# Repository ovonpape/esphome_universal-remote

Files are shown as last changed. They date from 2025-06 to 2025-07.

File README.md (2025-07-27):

# HassBeam
A cheap and easy to use universal remote that can be integrated into Home Assistant using ESPHome.  
It allows you to replace your pile of different remote controls with one stationary device that can be controlled via Home Assistant. Of course, you can also automate the control of your IR devices.

<p float="left">
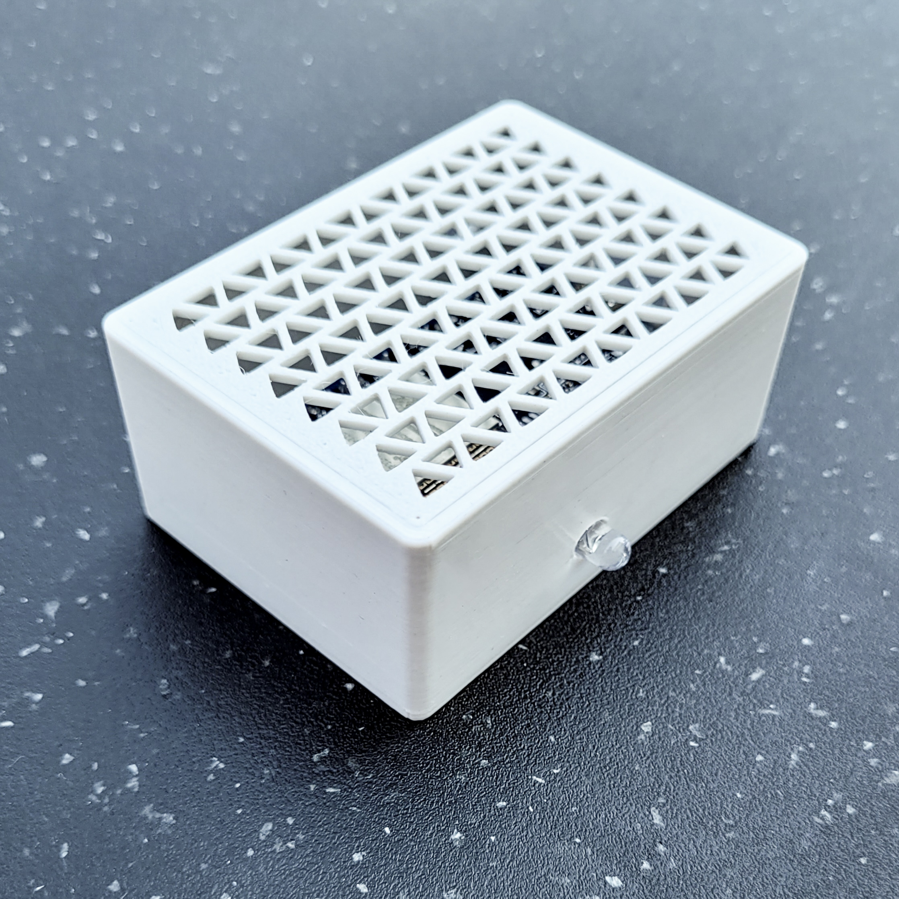
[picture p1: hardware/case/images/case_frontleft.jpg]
case_frontleft
  
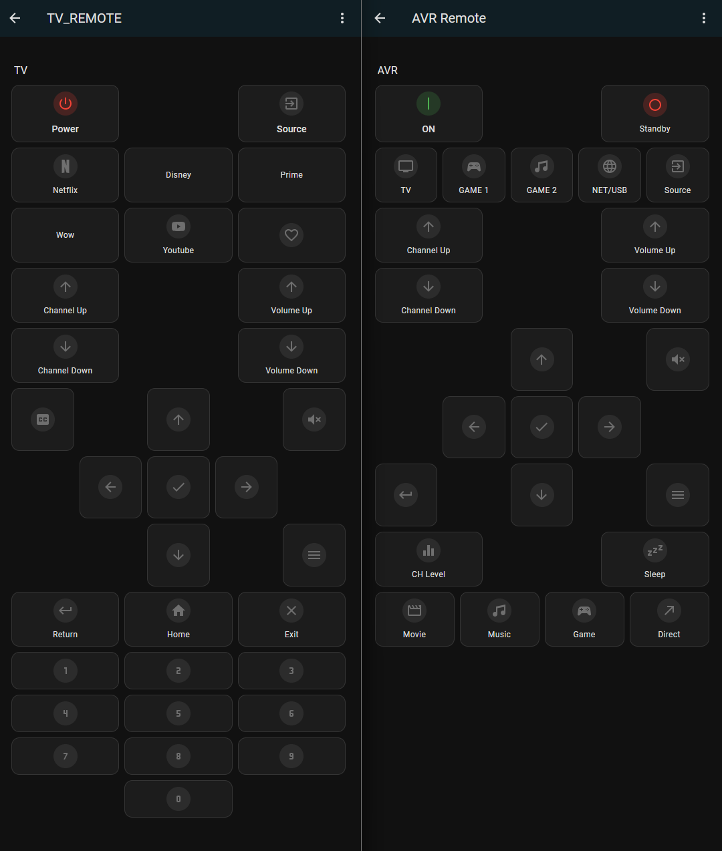
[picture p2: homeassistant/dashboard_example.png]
Dashboard Example
  
</p>

#### With the new [HassBeam Connect integration](#hassbeam-connect), configuring your system is faster and simpler than ever:
<p float="left">
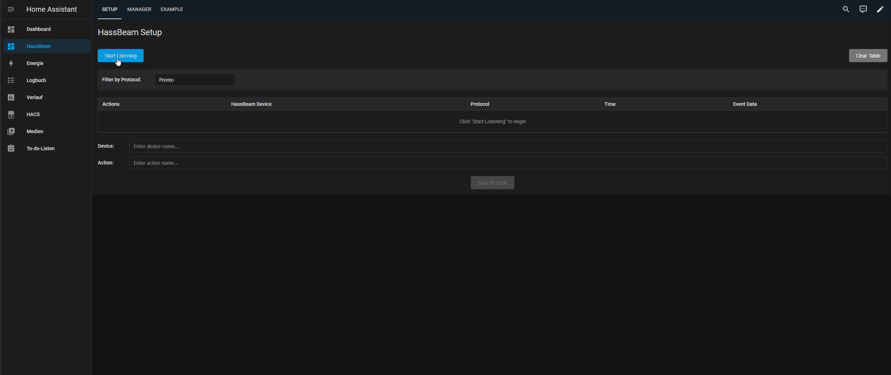
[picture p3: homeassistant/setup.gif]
setup process
  
</p>

## ✅  Requirements
To use this project, you will need a working [Home Assistant](https://www.home-assistant.io/) instance, as the universal remote integrates directly with it. The core of the device is an ESP micro controller, which communicates with Home Assistant via [ESPHome](https://esphome.io/).

In addition to the ESP, a few electronic components are required — see the [Parts](hardware.md#parts) section for details. 

Optionally, design files for a custom PCB or perfboard layout are provided, along with a 3D-printable case for the device.

<br>

## 🚀 Getting Started

To get started with the ESPHome Universal Remote, you will need to assemble the necessary hardware and flash the ESP32 with the appropriate configuration using ESPHome.

### ⚙️ Hardware Guide
The universal remote is fairly simple to build and use.  
Read the [Hardware Guide](hardware.md) for instructions on what you need and how to build it.

### 🛠️ Setup Guide

Once your hardware is ready, read the [Setup Guide](setup.md) to learn how to install and use the project.

<br>

## 💬 Community & Support

For questions, feature requests, or to connect with other users, feel free to join the discussion on [Reddit](https://www.reddit.com/r/HassBeam/).

You can use the thread to:
- Ask for help with setup or troubleshooting
- Share ideas or request new features
- Report issues (in addition to GitHub Issues)
- Showcase your own HassBeam related projects

We’d love to hear your feedback and see what you build!

<br> 
<br>
<br>

## 🔗 Related Projects

#### HassBeam Connect
A quick and easy way to capture and manage your IR codes in Homeassistant:
  - [HassBeam Connect Backend](https://github.com/BasilBerg/hassbeam-connect-backend)
  - [HassBEam Connect Cards](https://github.com/BasilBerg/hassbeam-connect-cards)
</br>

Check out these projects that helped in the creation of this project:
- [ESPHome](https://github.com/esphome/esphome)  
  Used to configure and flash the ESP32. Also handles IR signal sending and receiving.

- [Home Assistant](https://github.com/home-assistant/core)  
  Serves as the central control hub for triggering IR commands and integrating the remote into smart home automations.

- [Mushroom](https://github.com/piitaya/lovelace-mushroom)  
  A modern and customizable UI component library for Home Assistant dashboards, used in the example configuration to create clean remote interfaces.

- [Fritzing](https://github.com/fritzing/fritzing-app)  
  Used to create the wiring diagrams and PCB layout.

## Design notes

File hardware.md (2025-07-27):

# HassBeam – Hardware

## Contents

- [Parts](#parts)
- [Assembly Options](#assembly-options)
- [Case](#case)

---

## Parts

To build the ESPHome Universal Remote, you’ll need:

- **Resistors**  
  Limit current through the IR LED and transistor. In this build: 11 Ohms for the LED, 1k Ohms for the transistor and 100 Ohms for the IR-Receiver. Choose a value based on the datasheets of your components.

- **Capacitor** (optional)
  A capacitor is used to filter high frequency noise. this improves reliability of the IR Receiver but is completely optional. In this example I'm using a 100nF capacitor.

- **IR LED**  
  Emits the infrared signals. Use a 940 nm LED for best compatibility. Narrow beam for focused control, wide for room coverage.

- **NPN Transistor**  
  Used to drive the LED safely, as ESPs GPIO pins can't handle high current.

- **IR Receiver**  
  Allows reading commands from existing remotes. The carrier frequency of most common IR protocols is 38kHz, so the receiver you pick should support that. In this example I'm using a TSOP4838

- **ESP microcontroller**  
    Any ESP microcontroller supported by ESPHome can be used, but you may need to adjust the wiring and case design to accommodate differences in pin layout and physical dimensions. In this example, an ESP32 WROOOM32 devboard is used

- **(Optional) Pin Headers**  
  Useful for detachable power or signal connections. If you want to build multiple HassBeams, you can make the receiver circuit modular to save cost and make the device smaller.

---

## Assembly Options

### Breadboard / Perfboard

The circuit can be assembled on a breadboard for prototyping. For a more permanent installation, you can solder the components onto a perfboard or use a custom PCB.  
The images below serve as wiring references, and the included Fritzing file can be viewed or edited as needed.  

<p float="left">

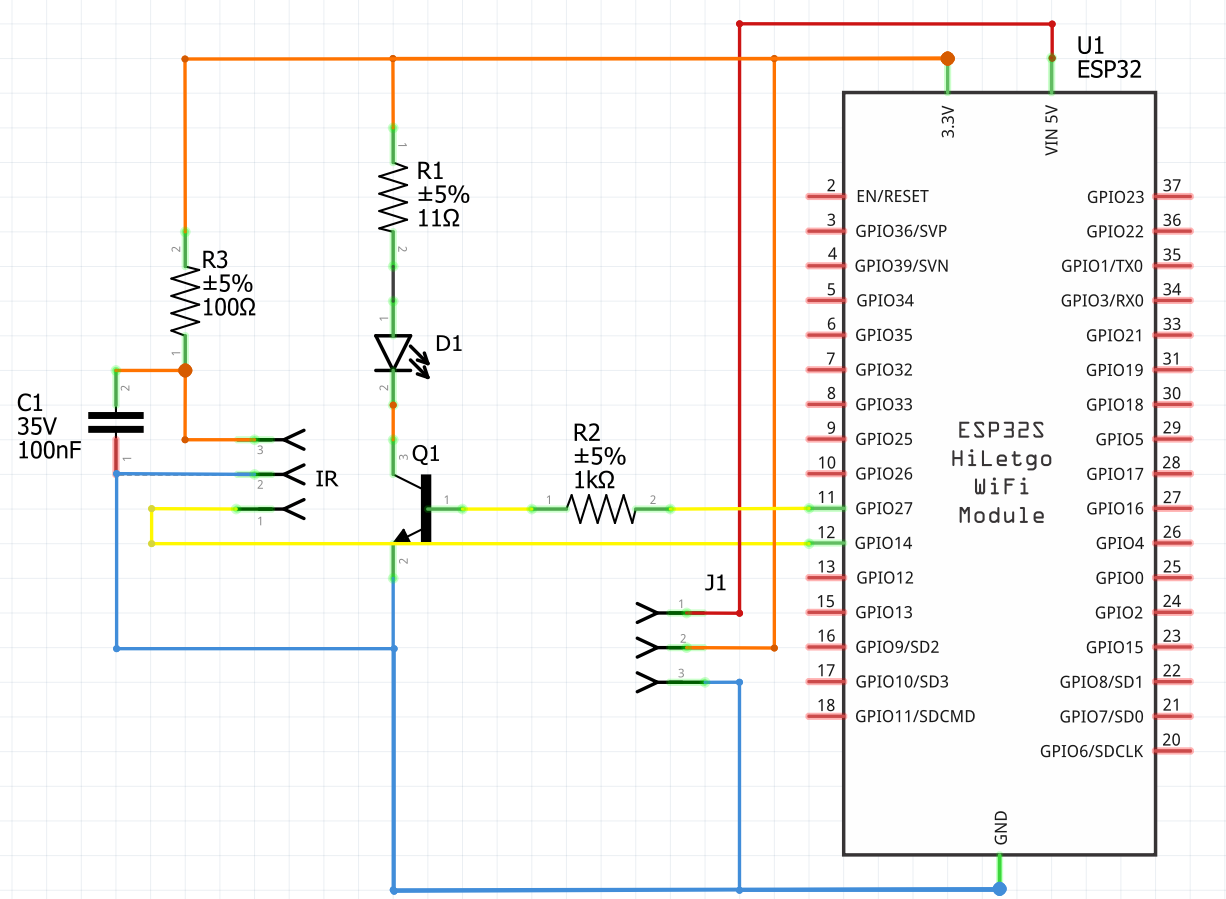
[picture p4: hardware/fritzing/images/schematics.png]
Schematics
  
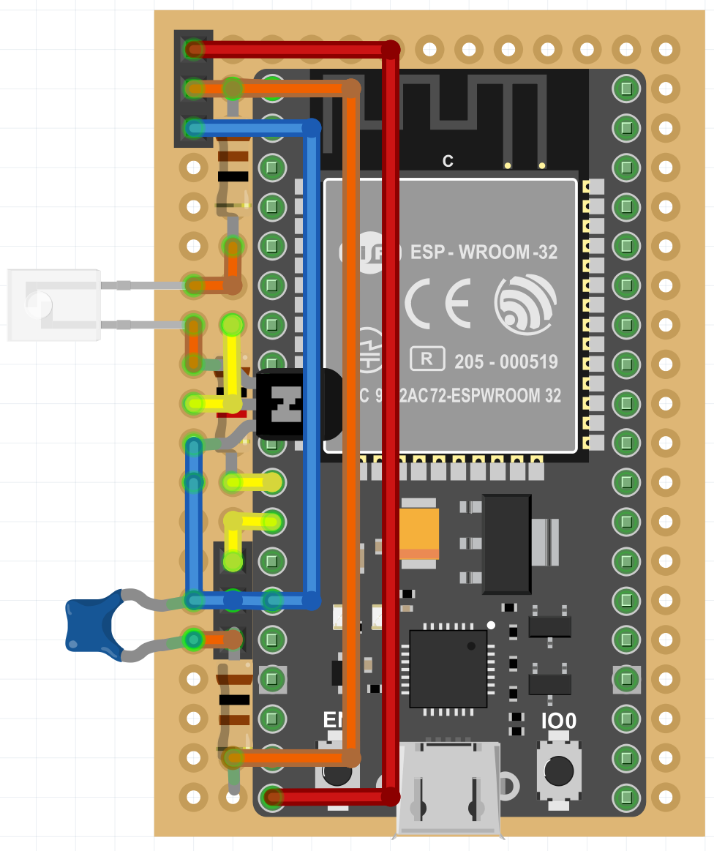
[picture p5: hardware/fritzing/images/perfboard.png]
Perfboard
    
</p>

### Custom PCB

A [PCB design is provided](hardware/PCB) with Gerber files ready for fabrication. The single layer layout is simple and affordable to order.
The provided board was not tested in combination with the provided case yet, so if you want to use them together please double check the dimensions before ordering.

<p float="left">
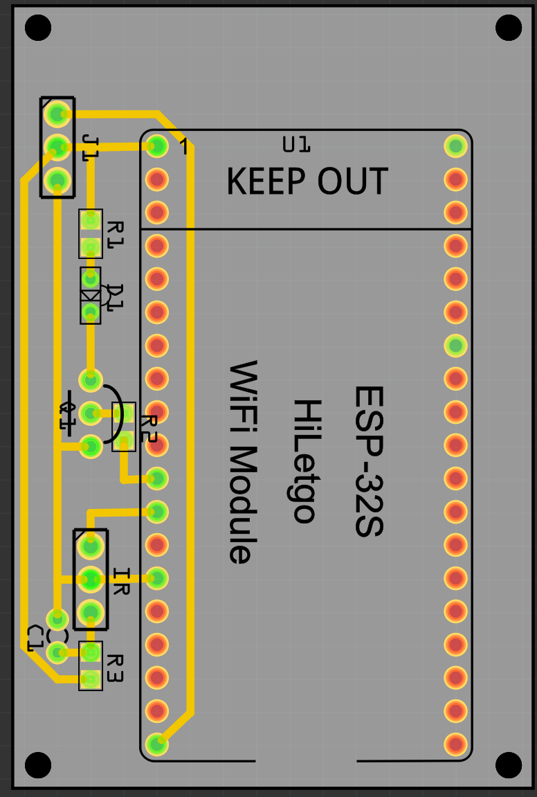
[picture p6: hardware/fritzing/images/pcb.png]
pcb
  
</p>
---

## Case

A 3D-printable case is available to protect and mount the remote. It’s optional but recommended for permanent or visible installations.
This case is intended for the use of an ESP32 development board and a 4 x 6 cm (in this case 14 x 20 holes) perf board or PCB.

### Download

The case is available in the following formats:

- [Fusion 360 - f3d](hardware/case/f3d)
- [Object File - obj](hardware/case/obj)
- [STEP - stp](hardware/case/stp)

### Pictures

<p float="left">
  case_frontleft
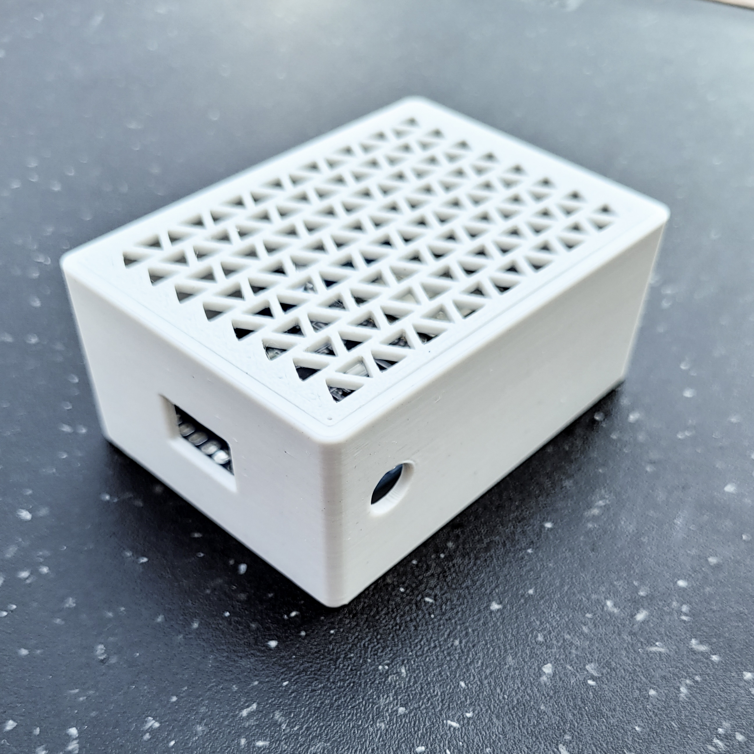
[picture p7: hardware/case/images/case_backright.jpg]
case_backright
  
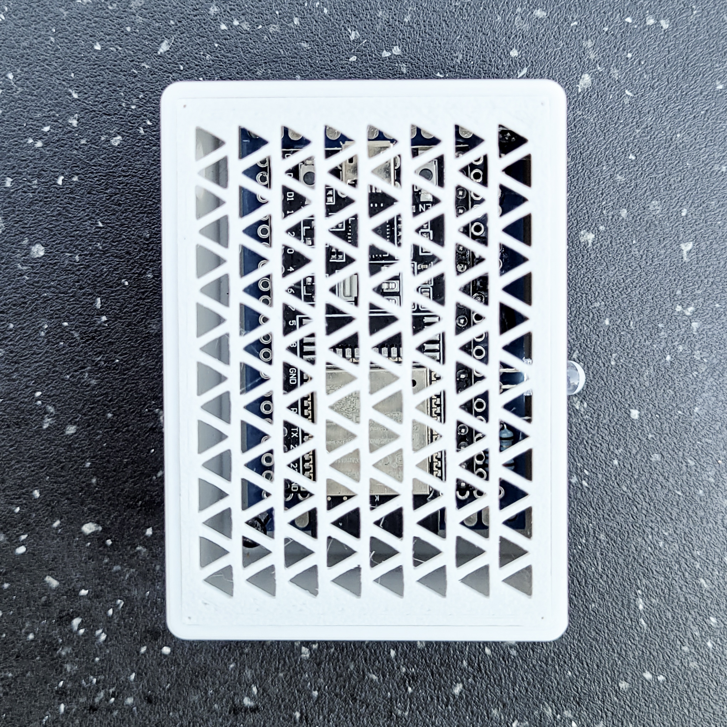
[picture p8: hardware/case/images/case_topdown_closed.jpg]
case_topdown_closed
  
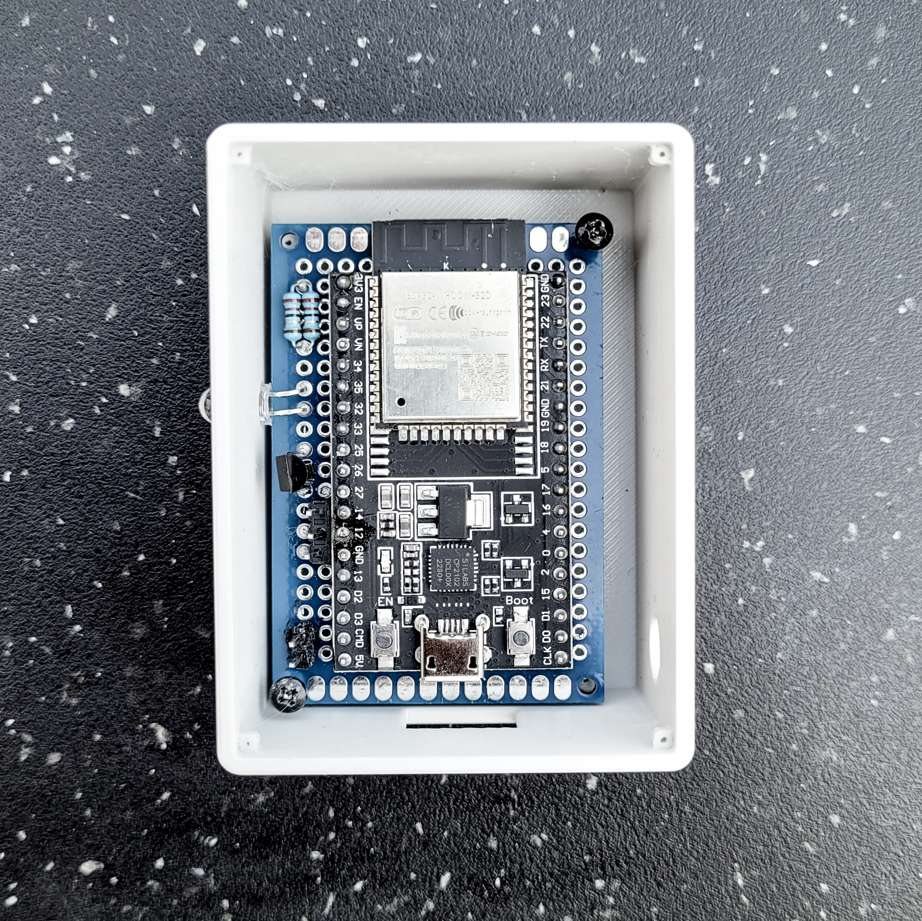
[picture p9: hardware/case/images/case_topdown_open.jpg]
case_topdown_open
  
</p>

### 🛠️ Setup Guide

Once your hardware is ready, continue with the [Setup Guide](setup.md) to learn how to install and use the project.

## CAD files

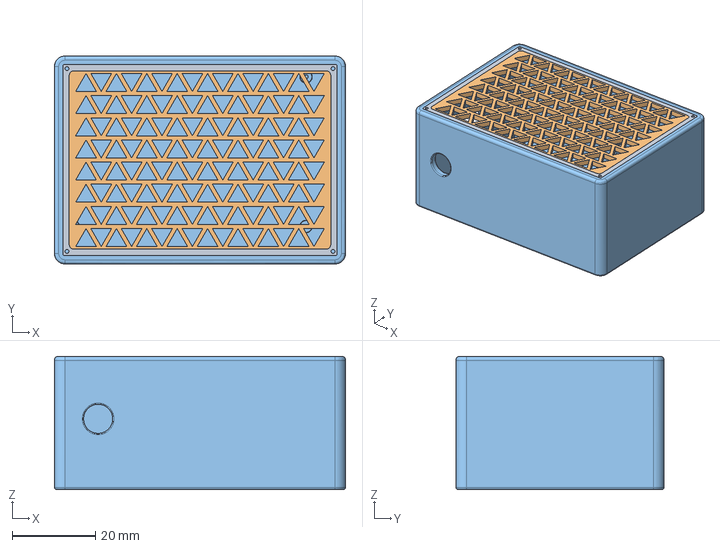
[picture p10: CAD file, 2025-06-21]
hardware/case/stp/universalremote v15.step
70.0 x 50.0 x 32.0 mm

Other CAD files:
hardware/case/f3d/universalremote v15.f3d

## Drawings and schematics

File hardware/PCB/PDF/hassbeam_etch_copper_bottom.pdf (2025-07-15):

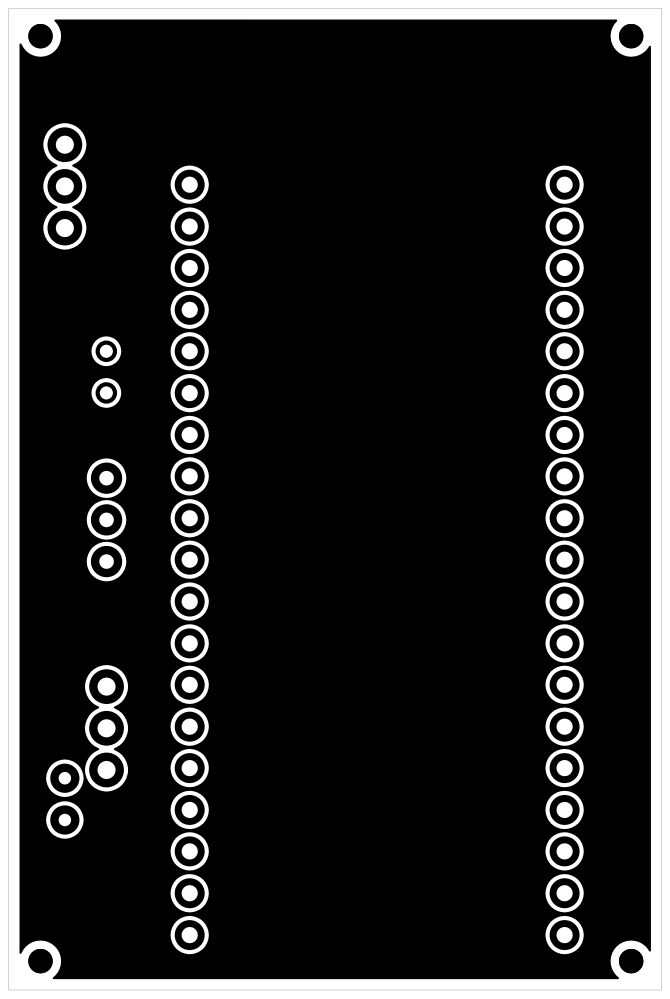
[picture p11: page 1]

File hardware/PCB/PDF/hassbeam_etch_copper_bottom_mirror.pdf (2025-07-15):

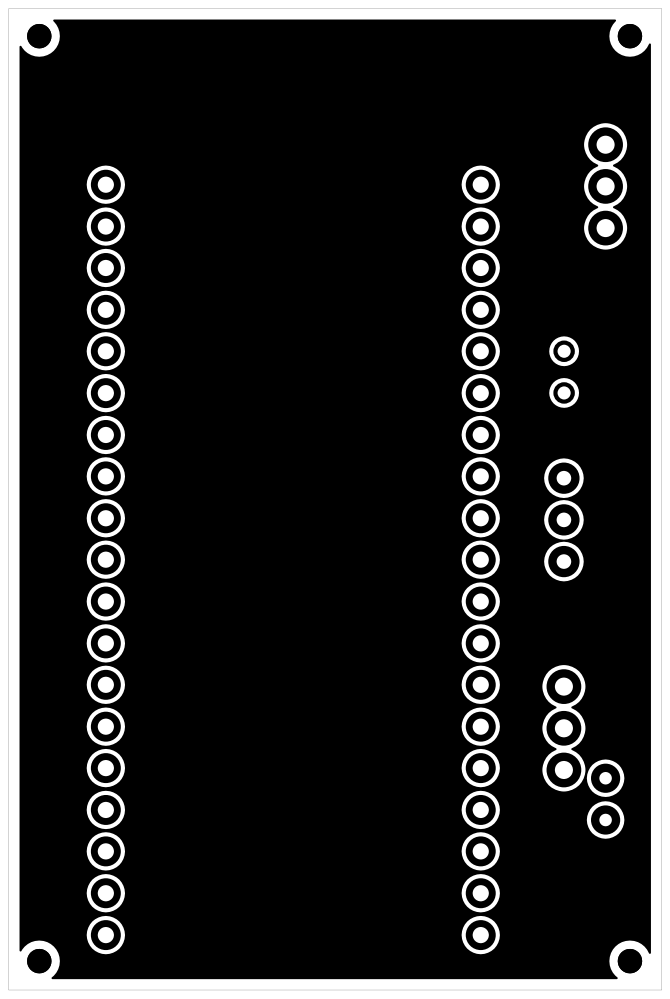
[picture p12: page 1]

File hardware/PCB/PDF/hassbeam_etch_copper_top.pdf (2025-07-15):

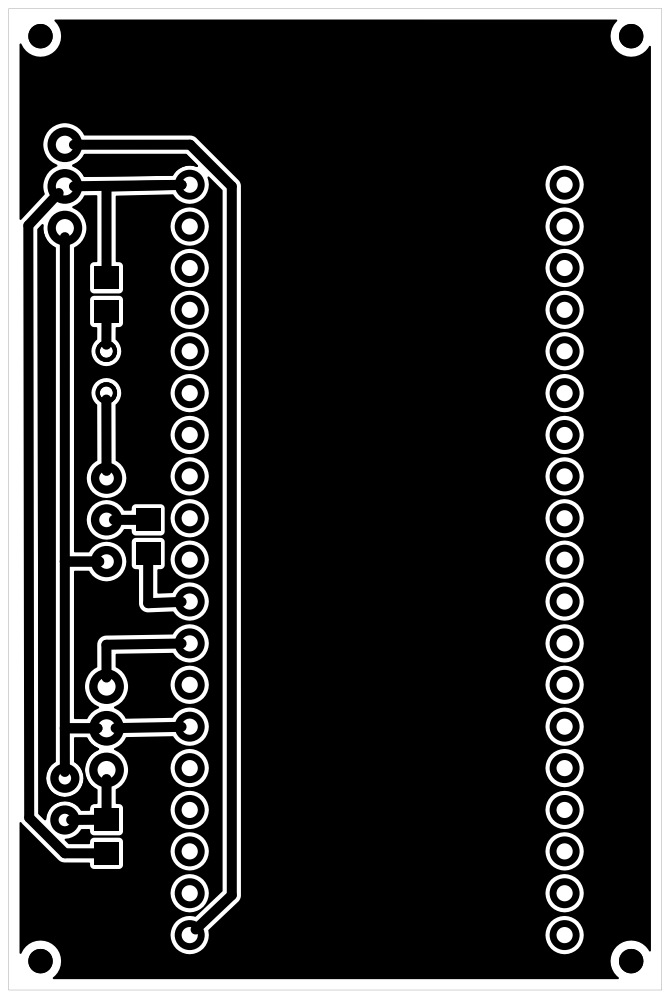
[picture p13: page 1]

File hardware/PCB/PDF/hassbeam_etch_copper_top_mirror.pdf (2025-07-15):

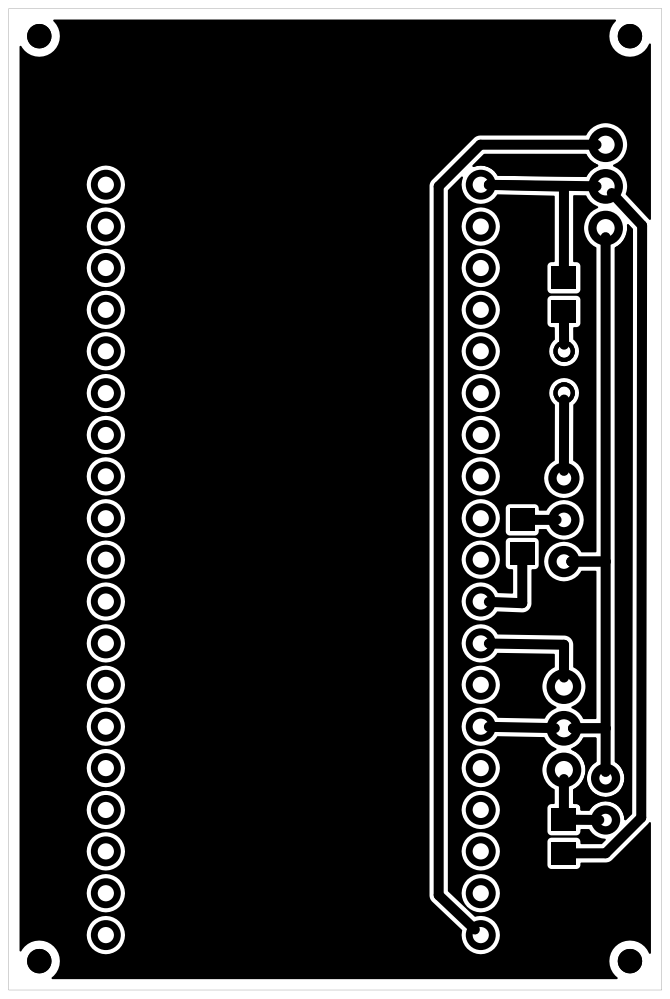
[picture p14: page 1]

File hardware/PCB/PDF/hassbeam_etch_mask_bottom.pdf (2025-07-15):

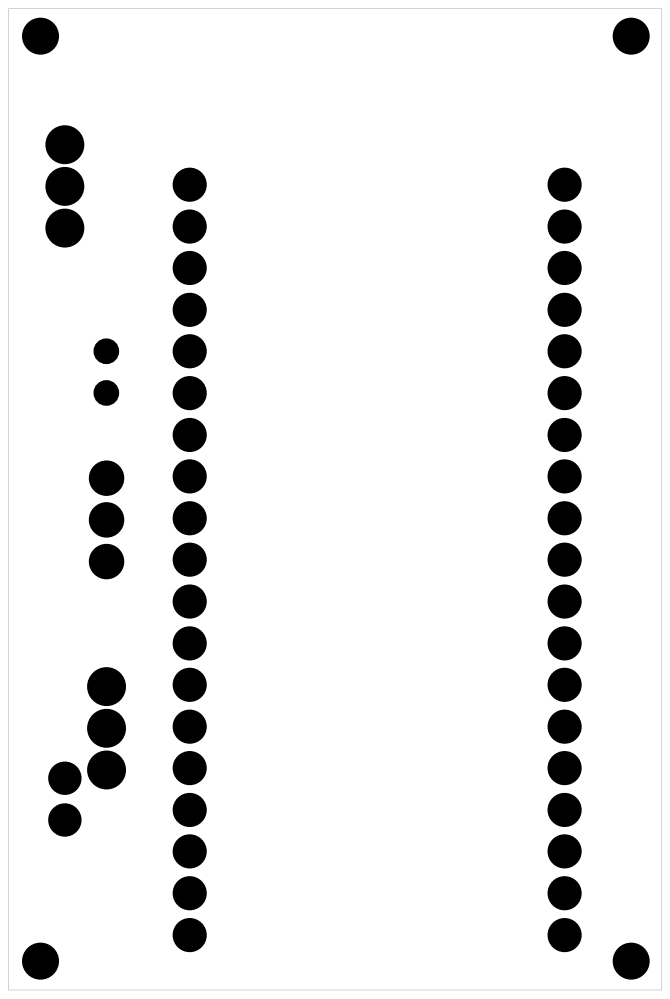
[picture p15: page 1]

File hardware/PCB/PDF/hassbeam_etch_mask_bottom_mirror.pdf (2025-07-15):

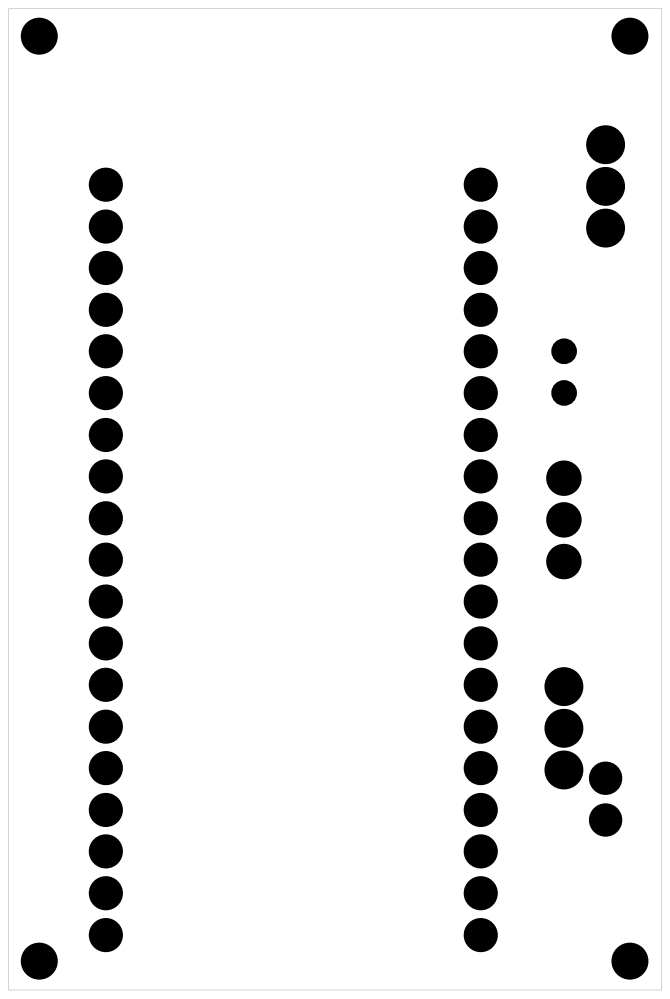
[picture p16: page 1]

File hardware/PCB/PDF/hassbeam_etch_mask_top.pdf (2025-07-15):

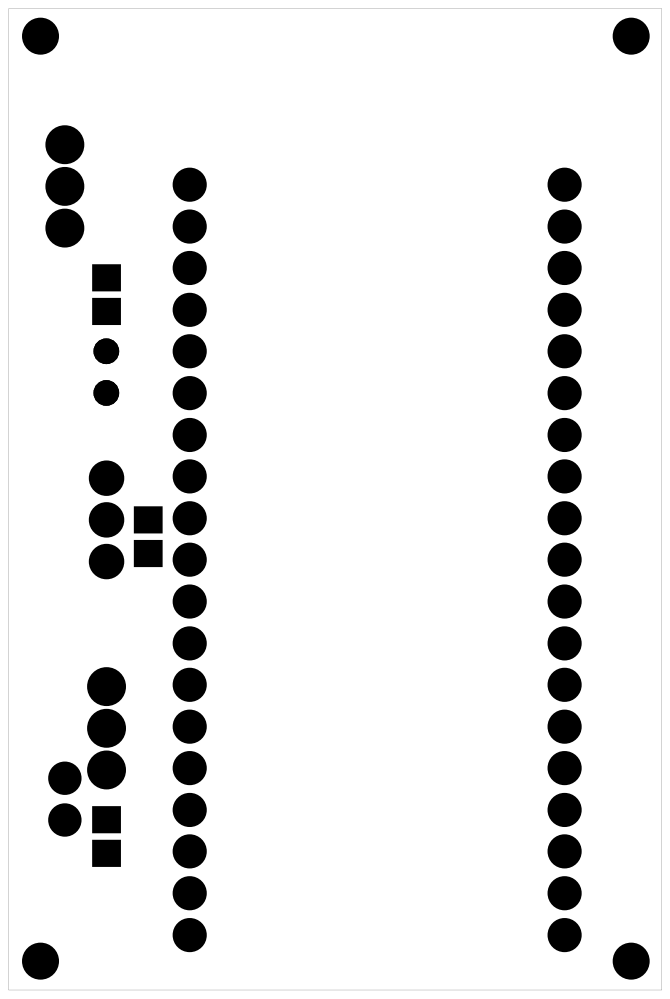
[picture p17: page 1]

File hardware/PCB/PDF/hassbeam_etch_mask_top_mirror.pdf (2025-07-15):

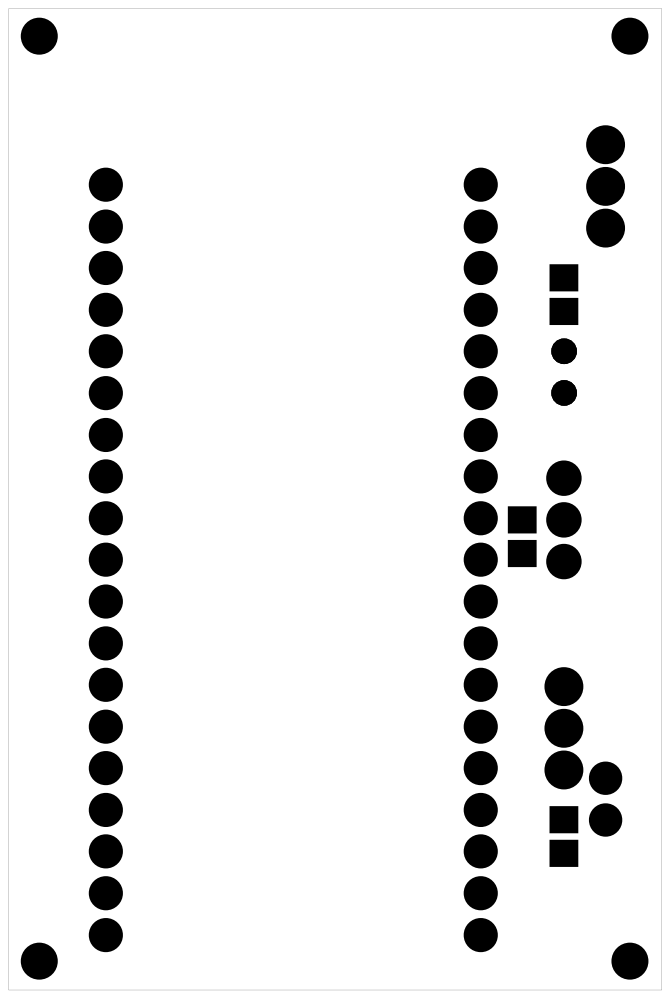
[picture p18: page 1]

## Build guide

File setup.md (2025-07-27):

# HassBeam – Setup

## Contents

- [Installation](#installation)
- [Capturing IR Commands](#capturing-ir-commands)
- [Home Assistant Setup](#home-assistant-setup)
  - [Creating Scripts to Send IR Commands](#creating-scripts-to-send-ir-commands)
  - [Creating a Dashboard to Control Devices](#creating-a-dashboard-to-control-devices)

<br>
<br>

---

### ⚙️ Hardware Guide
Before starting with the setup, read the [Hardware Guide](hardware.md) for instructions on what you need and how to build it.

## Installation

Clone this repository or download the latest release.

To install the the software on your ESP, first make sure to configure your Wi-Fi credentials.  
A sample configuration is provided in the [esphome folder](esphome). You just need to rename the file `secrets_template.yaml` to `secrets.yaml` and adjust it with your local SSID and password.  
After that you can flash the provided configuration file `hassbeam.yaml` using [ESPHome](https://esphome.io/). 

While the ESPHome device builder can be used directly within Home Assistant, **compilation on limited hardware can be extremely slow**. It's recommended to install and use the ESPHome CLI on a PC for faster builds and flashing. You can find installation instructions in the [ESPHome Getting Started guide](https://esphome.io/guides/getting_started_command_line.html).

#### ESPHome CLI (recommended)

- connect the device via USB (if wifi is already configured you can also use OTA instead of USB)
- open a terminal in the esphome folder
- run `esphome run .\hassbeam.yaml`
- select the proper device
- The code should now be compiled and flashed to the device

#### ESPHome Device Builder (not recommended for most cases)

- [Physically Connecting to your Device](https://esphome.io/guides/physical_device_connection#physically-connecting-to-your-device)
- [Device Builder](https://esphome.io/guides/getting_started_hassio#device-builder-interface)
- set the device builder secrets to the contents of `secrets_template.yaml`, make sure to fill in your wifi credentials 
- copy the code inside `hassbeam.yaml` and flash it to the device

<br>
<br>

---

## Home Assistant Setup

Once the ESP device is connected to your network, it should automatically be discovered by Home Assistant via ESPHome integration. If not, add it manually using its IP address (use the ESPHome integration).
<br>
<br>

---
## Capturing IR Commands
To make the setup process much faster and easier, you can use the HassBeam Connect Integration.
### Install HassBeam Connect
HassBeam Connect comes in two separate repos that contain the backend and frontend of the integration. You can install both manually but it is recommended to install them via [HACS](https://www.hacs.xyz/docs/use/download/download/)

- open HACS and click on the settings in the top right corner
- select custom repository
- add these two repositories:
  - [Backend](https://github.com/BasilBerg/hassbeam-connect-backend): `https://github.com/BasilBerg/hassbeam-connect-backend` Type: Integration 
  - [Lovelace Cards](https://github.com/BasilBerg/hassbeam-connect-cards): `https://github.com/BasilBerg/hassbeam-connect-cards` Type: Dashboard
- Search `HassBeam` in HACS and install `HassBeam Connect Backend` and `HassBeam Connect Cards`
- Go to Devices & Services and add the `HassBeam Connect Backend``Integration
- You can now add the `hassbeam-setup-card` and `hassbeam-manager-card` on any lovelace dashboard or use the [provided template dashboard](homeassistant/dashboard_hassbeam-connect_example.yaml)

### Using HassBeamConnect to capture commands
To capture IR commands you can use the `hassbeam-setup-card`.
- click Start Listening
- press the Button of the original remote
- the captured command(s) should now appear in the list
  - you can filter the list by protocol or leave this field empty to display all protocols
  - pronto is selected by default since it is not protocol specific and should work for all common devices
- Pick the command you want to save
  - if you're not sure which one will work, you can click send to replay the command and check if the device reacts as expected
  - click select on the command you want to save
- enter the name of the device this command controls
- enter the name of the action this command performs
- click Save IR Code

Setup process

## Managing stored commands
To capture IR commands you can use the `hassbeam-manager-card`. This card can display a list of all commands you have saved. you can filter them by target device or action and you can replay the command from within this list. You can also delete commands.
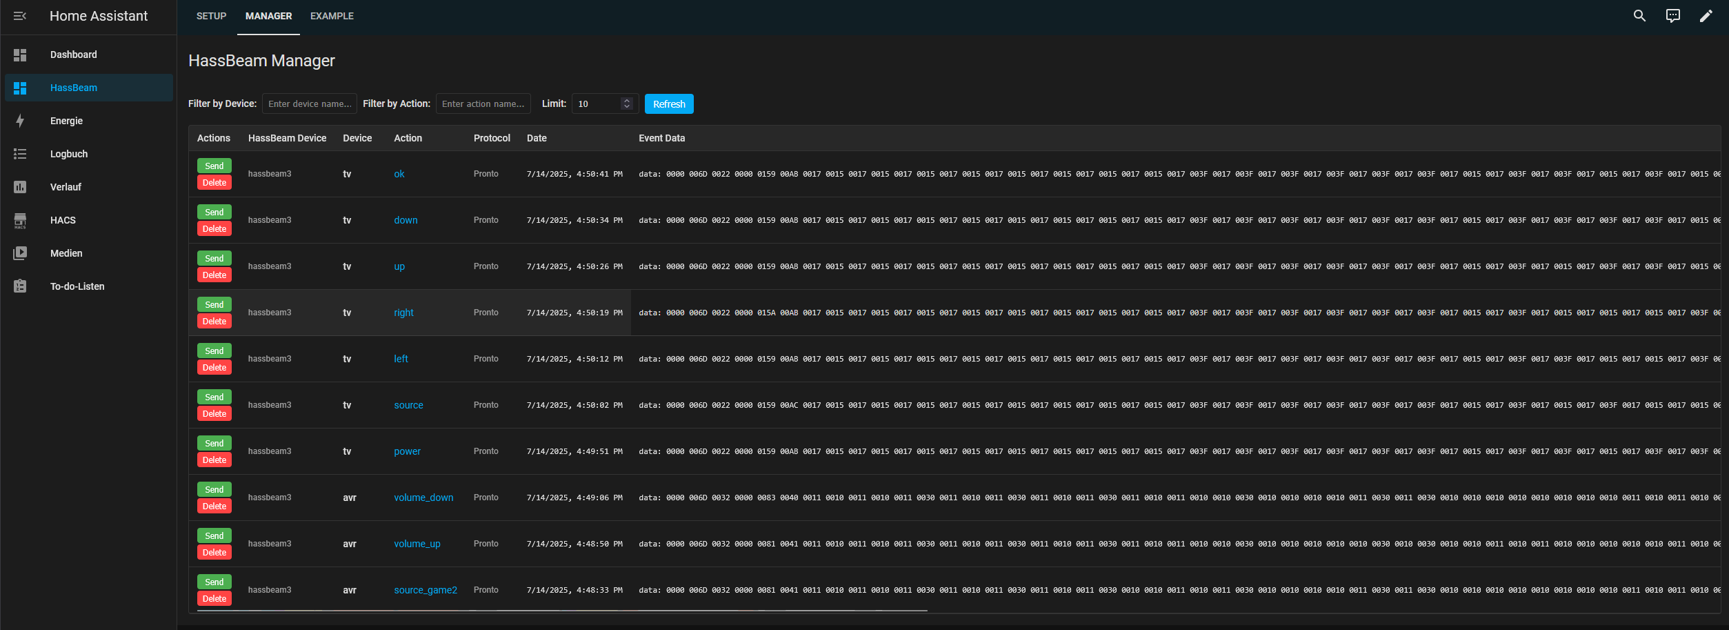
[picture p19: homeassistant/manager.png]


## Sending IR Commands
You can use the saved IR codes on your dashboard or inside scripts, automations etc. using the `hassbeam_connect_backend.send_ir_code` service.  
This can either be done in the UI:

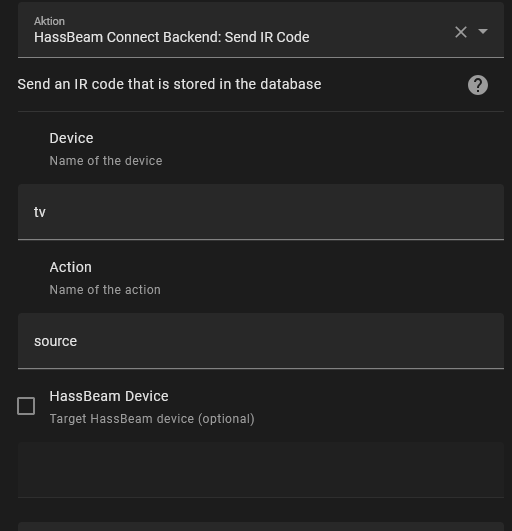
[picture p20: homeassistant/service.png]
UI Service call


or in YAML:

```yaml
action: hassbeam_connect_backend.send_ir_code
data:
  device: tv    #Device name you specified during setup
  action: power #Action name you specified during setup
```

<br>
<br>

---

### Creating a Dashboard to Control Devices

You can create a user interface in Home Assistant to trigger these commands. In the example setup, one dashboard page per remote is created (e.g., TV, AVR). The layout uses the [Mushroom](https://github.com/piitaya/lovelace-mushroom) custom cards from HACS for a clean and modern interface.

Example dashboard configurations are provided:

- [`dashboard_tv_example.yaml`](../homeassistant/dashboard_tv_example.yaml)
- [`dashboard_avr_example.yaml`](../homeassistant/dashboard_avr_example.yaml)

These can be imported or used as templates for your own setup.

Dashboard Example
---

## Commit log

2025-06-20 added esphome config, fritzing files, homeassistant config and README.MD
    [universal remote.fzz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]
2025-06-21 added files for 3d printing
    [universalremote v15.dxf, universalremote v15.f3d, universalremote v15.step]
2025-06-21 added readme files
    [universal_remote.fzz, universalremote v15.dxf]
2025-07-04 fixed wiring diagrams and naming
    [hassbeam.fzz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]
2025-07-15 updated schematics and perfboard/pcb layouts to integrate the receiver permanently into the circuit
    [hassbeam.fzz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]
